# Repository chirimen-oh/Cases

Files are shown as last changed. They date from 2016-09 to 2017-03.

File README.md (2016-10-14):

# Cases
CHIRIMEN Board Case Repository / CHIRIMENボード用ケースリポジトリ

## ケースリポジトリの手順について
1. issueを作る
1. fork して pull-req  or  ブランチ して pull-req
1. Merge する
1. 基本的にmaster は、直接いじらない

※chirimen-oh.github.io と手順は同じ

----

# コード名の命名について

1. コード名はケース作者（デザイナー）が任意の段階で決める。先に決めておくことが望ましい
2. コード名に商標等権利が発生する言葉を含めてはならない（「CHIRIMEN」も含めて）
3. コード名に公序良俗に反する言葉を含めてはならない
4. コード名に既に登録されている他のケースと全く同じ名前は使わない
5. コード名に利用可能な文字は英数字及び`-`、`_`のみとする

# その他

## フォルダ名とreadme.md

- フォルダ名はコード名とする
- フォルダ名の直下に`readme.md`を配置する

`readme.md`にはケースの設計情報や作り方などの情報の他に、

1. ケースのコード名
2. 作者（デザイナー）
3. ステータス（作成中なのか、作成完了なのか）
4. ライセンス
5. ケースの簡単な紹介（特徴など）
6. ケースの組み立てマニュアル

上記内容を記載する事。

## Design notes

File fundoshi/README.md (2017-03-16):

---
case name: fundoshi
designer: D.F.Mac. (H.Kodama)
version: 0.12
status: Draft
---

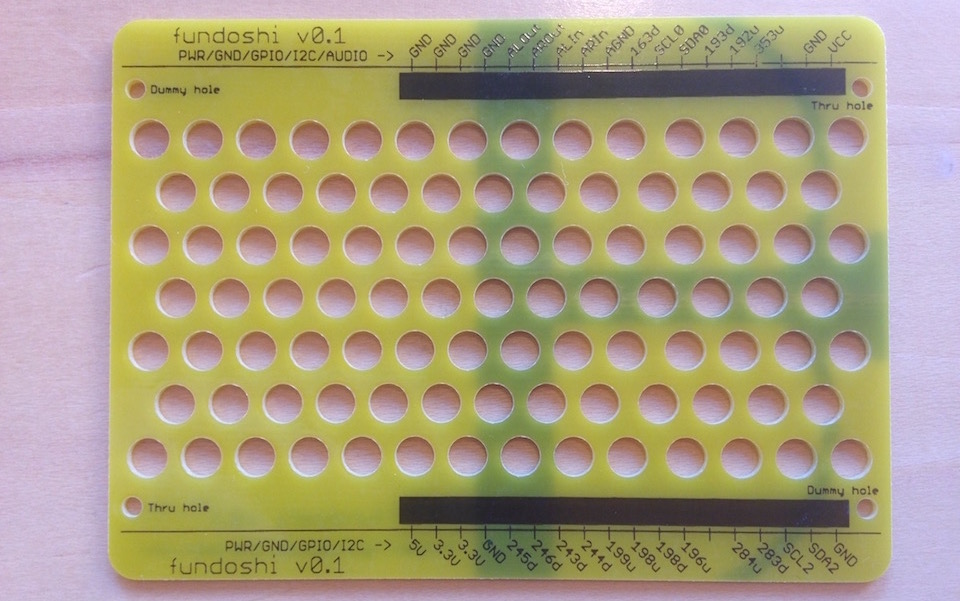
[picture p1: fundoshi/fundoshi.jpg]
fundosi-image


## desc

`fundoshi`はPCB1枚だけのシンプルなケースです。
上部は何もカバーせず底部のみカバーします。

## errata

v0.1及びv0.11にはFundoshiの印字に下記誤りがあります。

> v0.1のみ
>
> - CH1-8 が `198d` となっているが、`197d`の誤り
>
> v0.1、v0.11共通
> CH1-4 が `283d` となっているが、`283u`の誤り
> CH1-5 が `284u` となっているが、`284d`の誤り

上記誤りはv0.12で修正しています。

## design

Eagle 7.5で作成しています。詳細は下記を参照ください。

- [board(v0.12)](./eagle/CHIRIMEN-Fundoshi.brd)
- [Schematic(v0.12)※ブランクデータです](./eagle/CHIRIMEN-Fundoshi.sch)

### garber files

[Elecrow](https://www.elecrow.com/)用に出力したgarberファイルです。

- [v0.12](./garber-elecrow/v0.12)

## Make

[CHIRIMENにfundoshiを装着する (fabble)](http://fabble.cc/tadfmac/chirimen-fundoshi)

## License

[CHIRIME License](https://chirimen.org/license/)を参照ください。

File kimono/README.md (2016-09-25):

---
case name: kimono
designer: klaus (T.Fujieda)
version: 1.0
status: Publish
---

## desc

`kimono`はコンパクトなケースです。

アクリルボード4枚とボルト・ナットを使用してタフながら、各コネクタやピンにアクセスしやすくデザインされています。

case name「kimono」は、 [D.F.Mac.](https://github.com/tadfmac) 様に拝名をいただきました。

## design

Illustraorで設計し、レーザーカッターでアクリル加工しています。

- [Illustraor .ai](./chirimen_case4.ai)
- [Illustraor .svg](./chirimen_case4.svg)

### Parts

組み立てには下記パーツが必要です。

- 天板表(アクリル) ×1
- 天板裏(アクリル) ×1
- サイドステー(アクリル) ×2
- ボルト(2mm径) 長さ (15mm) ×3
- ボルト(2mm径) 長さ (8mm) ×1
- ボルト(2mm径) 長さ (6mm) ×2
- ナット(2mm径) 長さ (1.6mm) ×2
- ナット(2mm径) 長さ (3mm) ×9
 
2mm径長さ15mmのボルトは金属製しかないようです

## License

[Creative Commons License BY-SA 4.0 International](https://creativecommons.org/licenses/by-sa/4.0/deed.ja)

CHIRIMENの商標使用については、[CHIRIME License](https://chirimen.org/license/)を参照ください。

## README English
* Proto Type Case Making Process : [making-case-process-en.md](making-case-process-en.md)
* Parts List : [partsList-en.md](partsList-en.md)
* Assembly Process : [Assembly-procedure-en.md](Assembly-procedure-en.md)
* adobe illustrator Files : [chirimen_case4.ai](chirimen_case4.ai)
* SVG Files : [chirimen_case4.svg](chirimen_case4.svg)
* Case Build jpeg : [chirimen_case_build.jpg](chirimen_case_build.jpg)
* Case Build svg : [chirimen_case4_build.svg](chirimen_case4_build.svg)

## README 日本語
* 試作ケース製作プロセス：[making-case-process-ja.md](making-case-process-ja.md)
* パーツリスト：[partsList-ja.md](partsList-ja.md)
* 組み立て手順：[Assembly-procedure-ja.md](Assembly-procedure-ja.md)
* adobe illustrator ファイル：[chirimen_case4.ai](chirimen_case4.ai)
* SVG ファイル：[chirimen_case4.svg](chirimen_case4.svg)
* ケース組立図 jpeg形式：[chirimen_case_build.jpg](chirimen_case_build.jpg)
* ケース組立図 svg形式：[chirimen_case4_build.svg](chirimen_case4_build.svg)

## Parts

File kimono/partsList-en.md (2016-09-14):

## Parts list

### ◆ Acrylic board parts

| parts | number of need |
|:---|---|
| Acrylic Board (front : Logo) | 1 |
| Acrylic Board (back : Exhaust heat duct) | 1 |
| Side stay | 2 |

### ◆ Assembly parts

| parts | length:standard | diameter:standard  | number of need | site |
|:---|---|---|---:|:---:|
| Pan head mini screw | 15mm | M2:2mm | 3 | https://www.monotaro.com/p/0550/6977/ |
| POM Hexagonal nut spacers AS(Duracon)(packs) | 3mm | M2:2mm | 9 | https://www.monotaro.com/p/4226/3207/ |
| SPC-P Resin screw(PC/Pan head mini screw with a cross hole) | 6mm | M2:2mm | 2 | https://www.monotaro.com/p/4926/4993/ |
| (+)Pan head mini screw(Polycarbonate (transparency))  | 8mm | M2:2mm | 1 | https://www.monotaro.com/p/3579/5261/ |
| Hexagonal Nat 2 kind (stainless steel)  | 1.6mm | M2:2mm | 2 | https://www.monotaro.com/p/4221/7524/ |

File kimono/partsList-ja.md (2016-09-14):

## Parts list

### ◆ アクリル板パーツ

| パーツ | 必要個数 |
|:---|---|
| 天板（表：ロゴ） | 1 |
| 天板（裏：排熱ダクト） | 1 |
| サイドステー | 2 |

### ◆ 組み付けパーツ

| パーツ | 長さ：規格 | 径：規格  | 必要個数 | サイト |
|:---|---|---|---:|:---:|
| なべ小ねじ | 15mm | M2:2mm | 3 | https://www.monotaro.com/p/0550/6977/ |
| POM 六角両雌ねじスペーサー AS(ジュラコン)(パック品) | 3mm | M2:2mm | 9 | https://www.monotaro.com/p/4226/3207/ |
| SPC-P 樹脂ねじ(PC/十字穴付きなべ小ねじ) | 6mm | M2:2mm | 2 | https://www.monotaro.com/p/4926/4993/ |
| (+)鍋小ネジ(ポリカーボネート(透明))  | 8mm | M2:2mm | 1 | https://www.monotaro.com/p/3579/5261/ |
| 六角ナット 2種(ステンレス) | 1.6mm | M2:2mm | 2 | https://www.monotaro.com/p/4221/7524/ |

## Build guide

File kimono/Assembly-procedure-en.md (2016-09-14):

## Assembly Steps
1. About Parts
  * [Parts Lists](partsList-en.md) is Referred.
1. A board and acrylic parts are lined up.
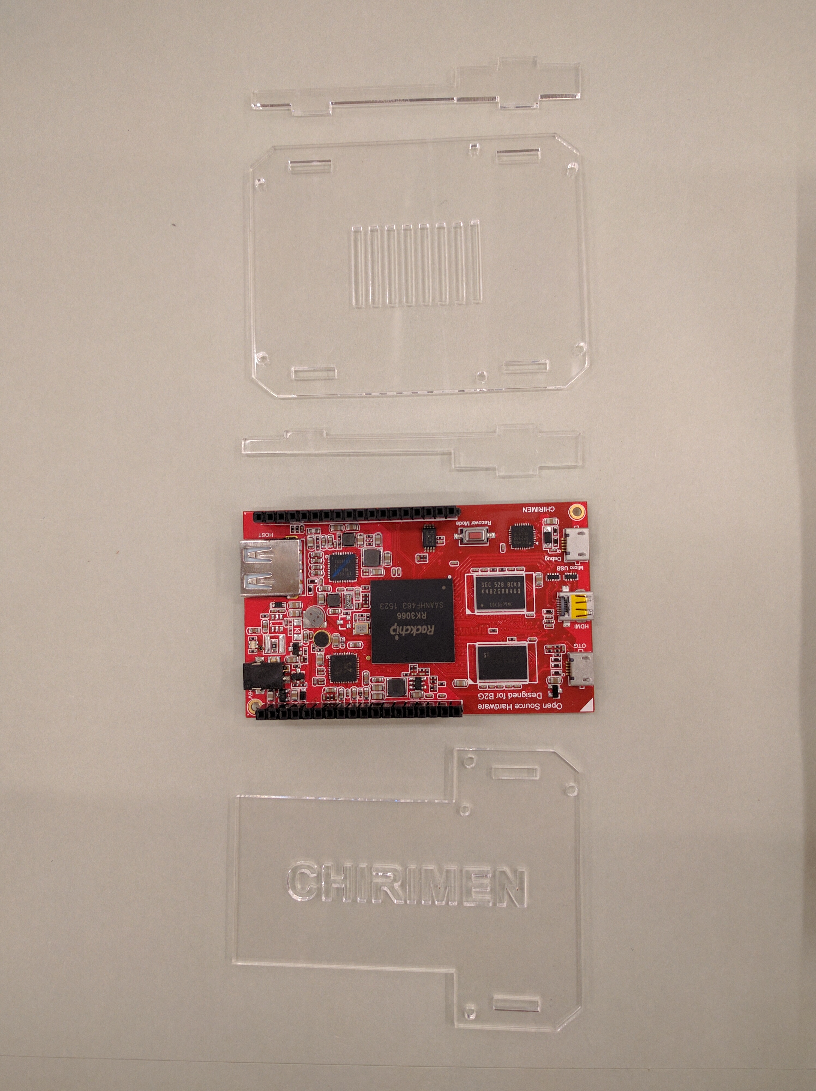
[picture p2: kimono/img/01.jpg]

1. Side stay is putted in Board (back : Exhaust heat duct) .
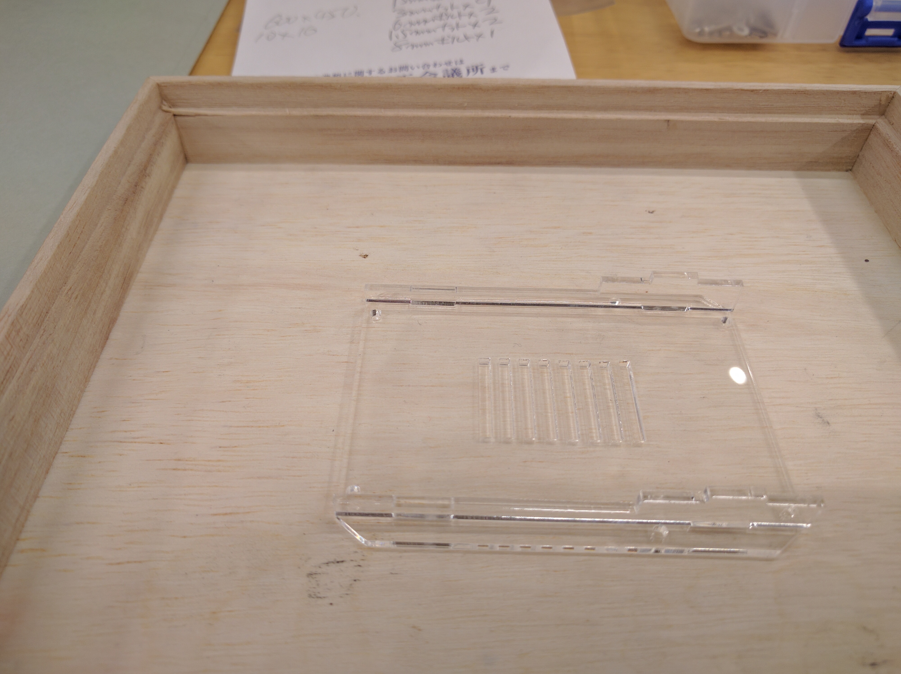
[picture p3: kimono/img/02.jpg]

1. Nuts and screw is used Assembly parts.
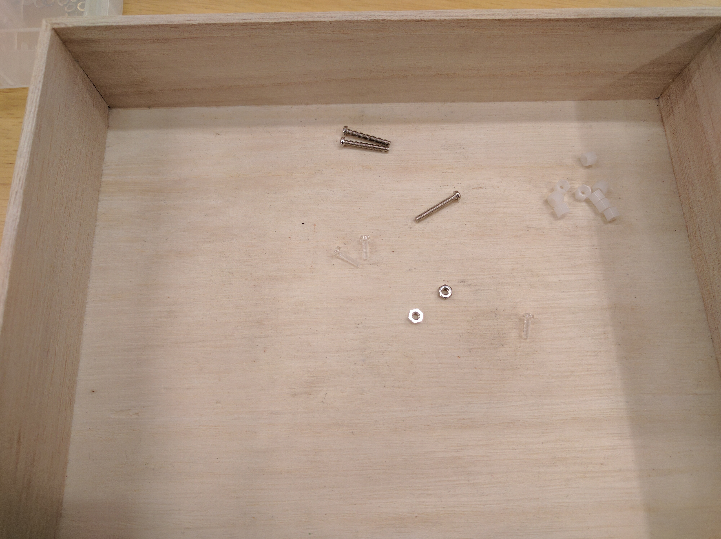
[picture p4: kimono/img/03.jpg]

1. 6mm length screw(2) is putted on Metal Nuts each 1.
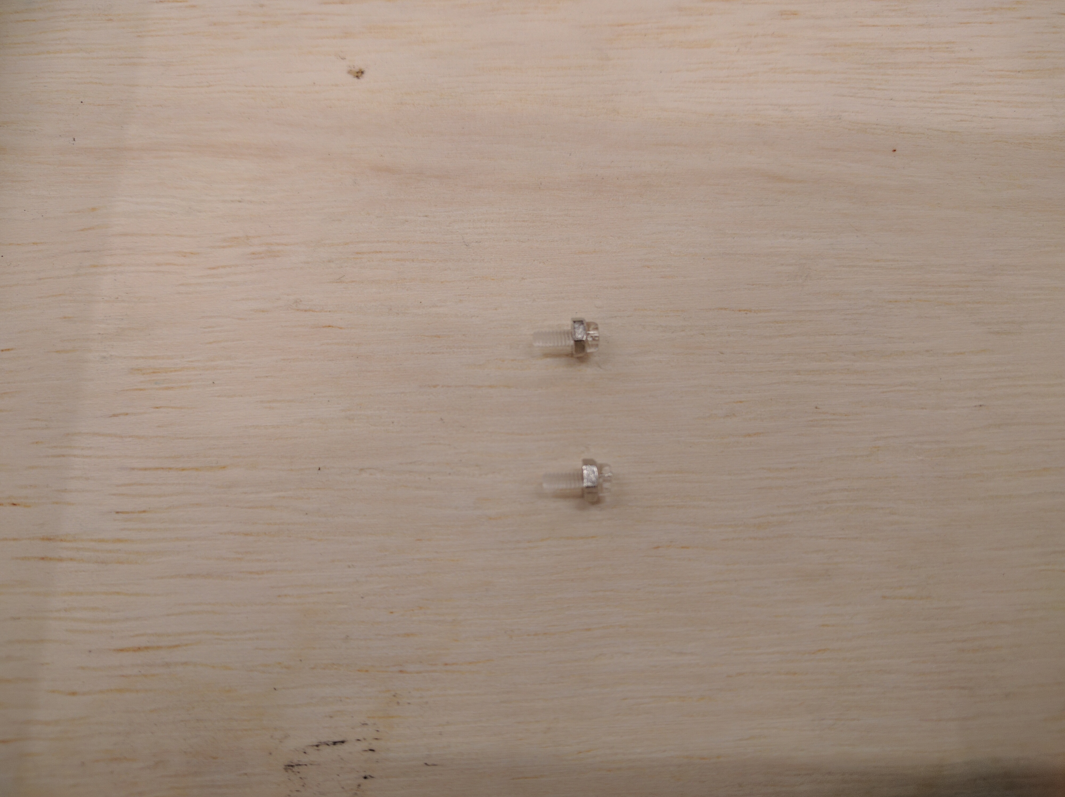
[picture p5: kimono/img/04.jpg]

1. 6mm length screw(2) is putted in Board (back : Exhaust heat duct) .
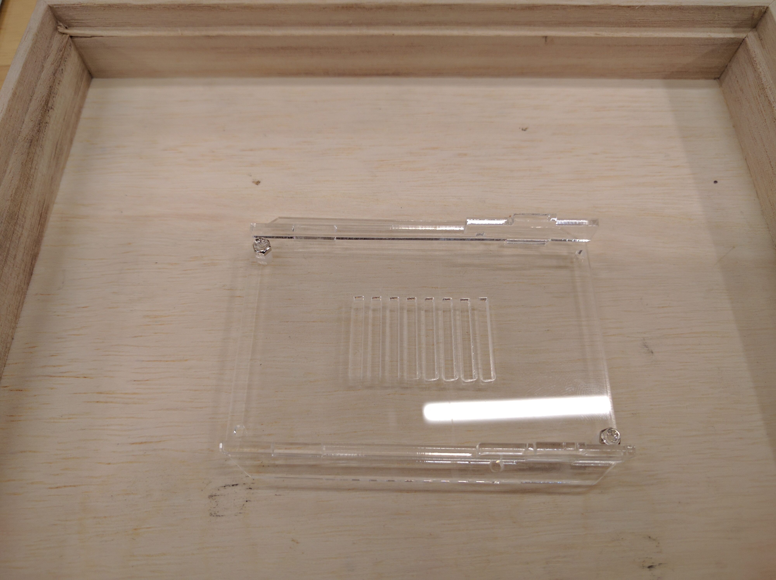
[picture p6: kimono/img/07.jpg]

1. Board (back : Exhaust heat duct) is reversed, White Nuts is putted on screw.
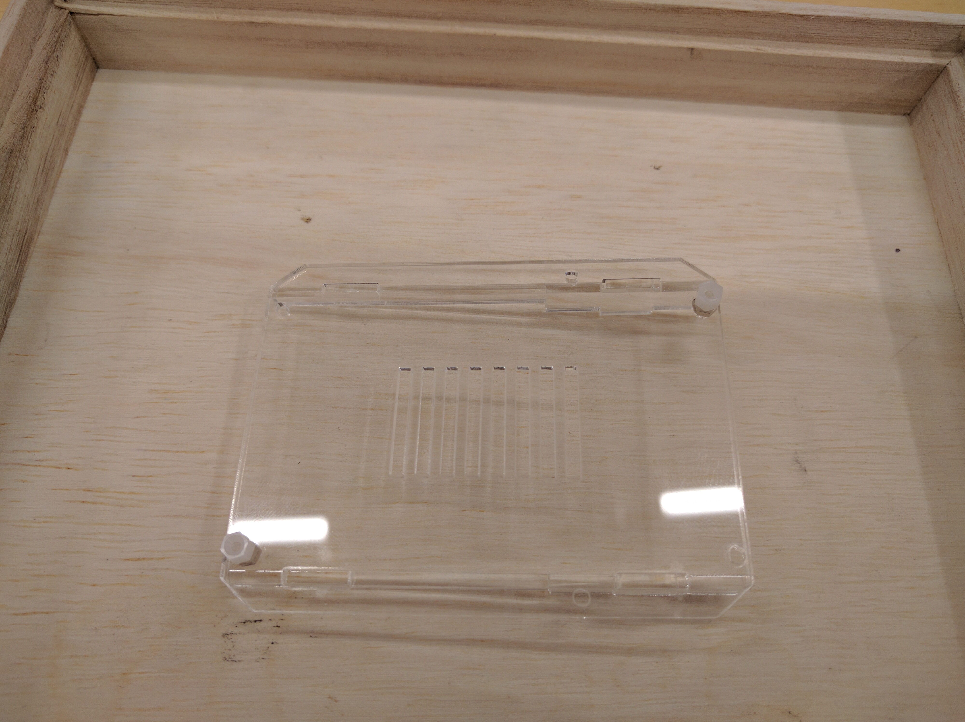
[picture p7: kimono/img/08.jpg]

1. 6mm length screw is putted at Around the point of a CHIRIMEN board Power Supply.
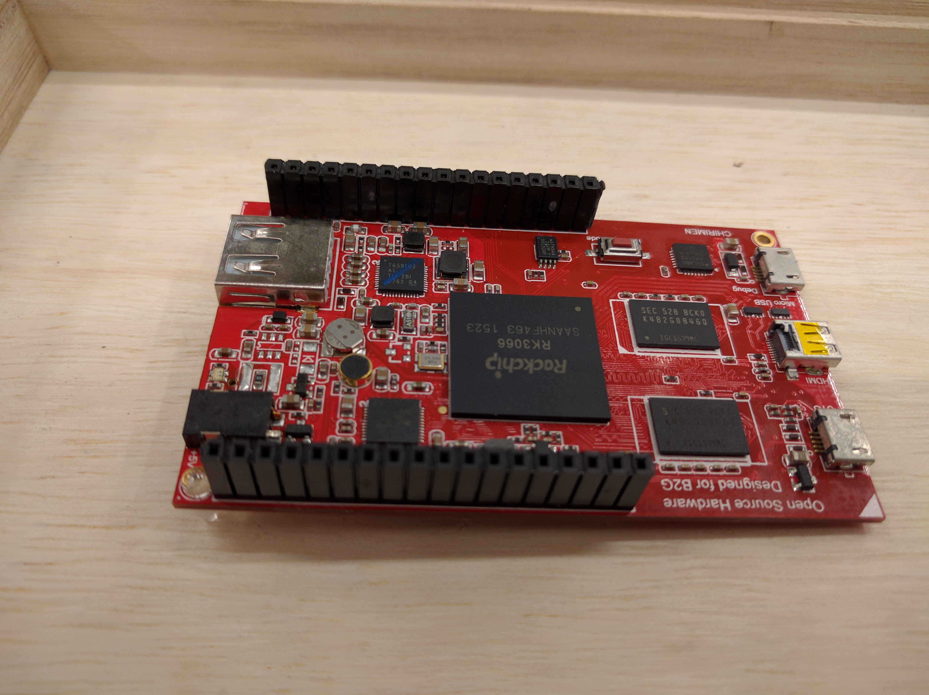
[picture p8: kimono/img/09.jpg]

1. CHIRIMEN Board is reversed, White Nuts is putted on screw.
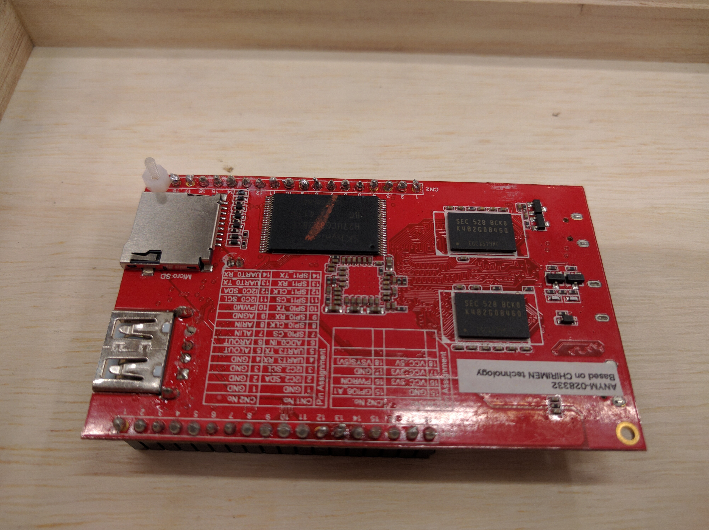
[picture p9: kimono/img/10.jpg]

1. Board (front : Logo) and 15mm screw(1) White Nuts(2) stand by.
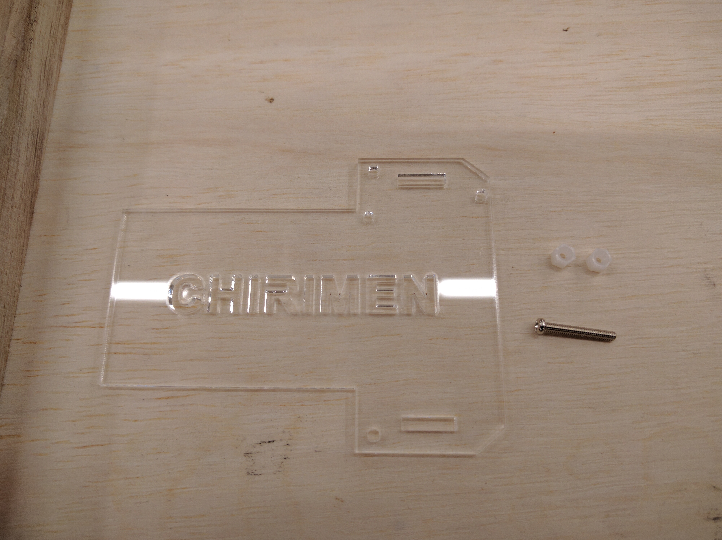
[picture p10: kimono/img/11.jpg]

1. Like a Under Picture, Board (front : Logo) is putted in 15mm length screw(1) ,  
   After White Nuts is putted on screw.
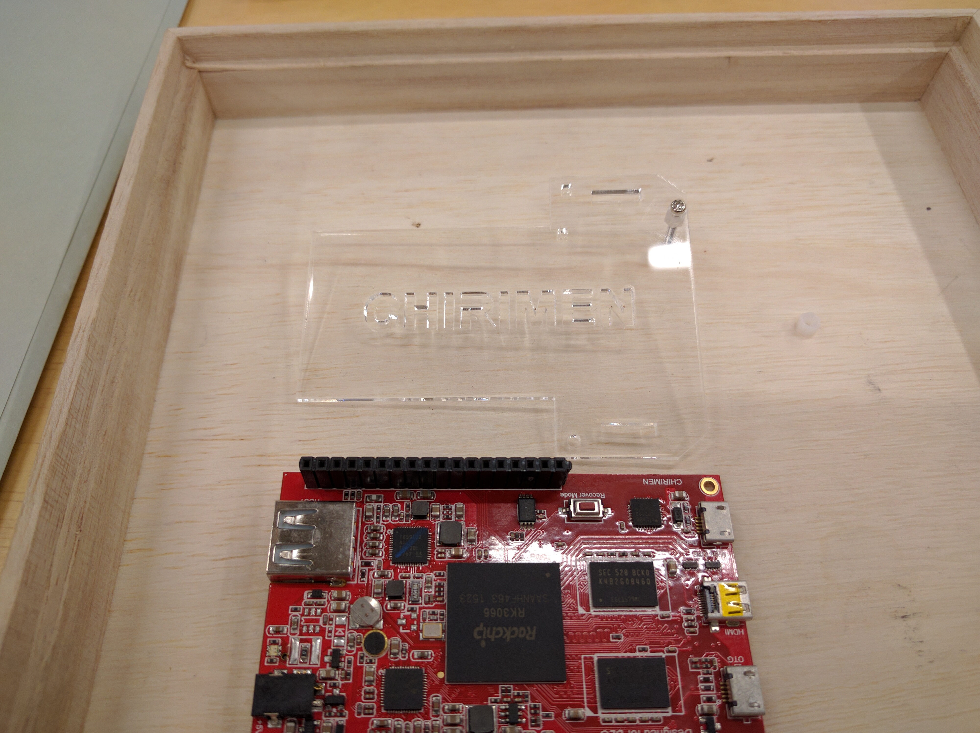
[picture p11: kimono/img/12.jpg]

1. And More, Like a Under Picture, Board (front : Logo) is putted in Hole of Recover Mode SW Right Side,  
  After White Nuts is putted on screw.
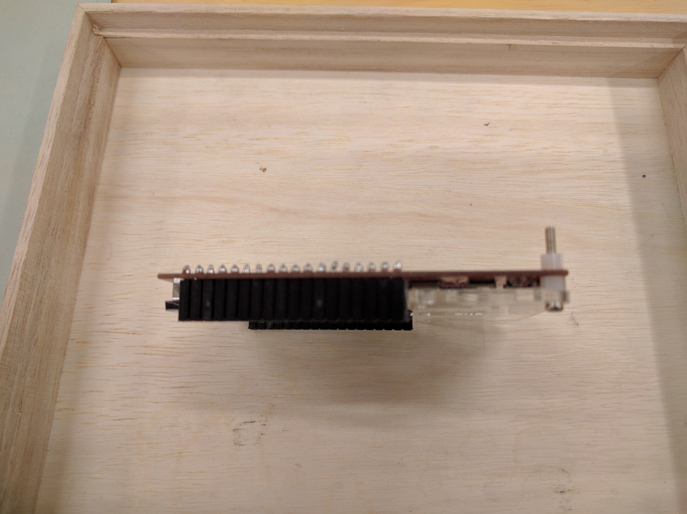
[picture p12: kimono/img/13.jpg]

1. CHIRIMEN Board is reversed, Like a Under Picture.
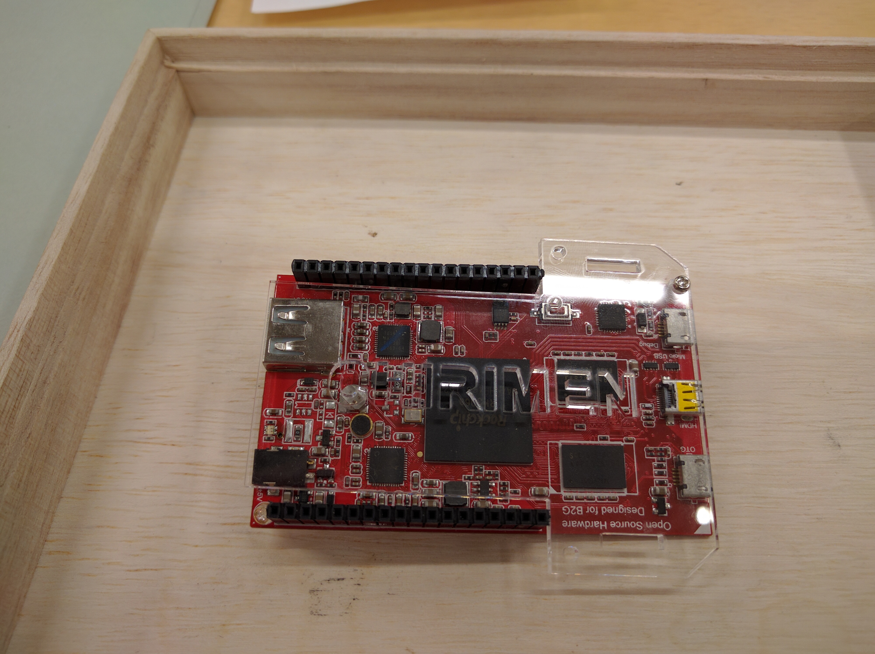
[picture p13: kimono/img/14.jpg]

1. Board (front : Logo) and Board (back : Exhaust heat duct) is picked up.  
  Like a Under Picture.
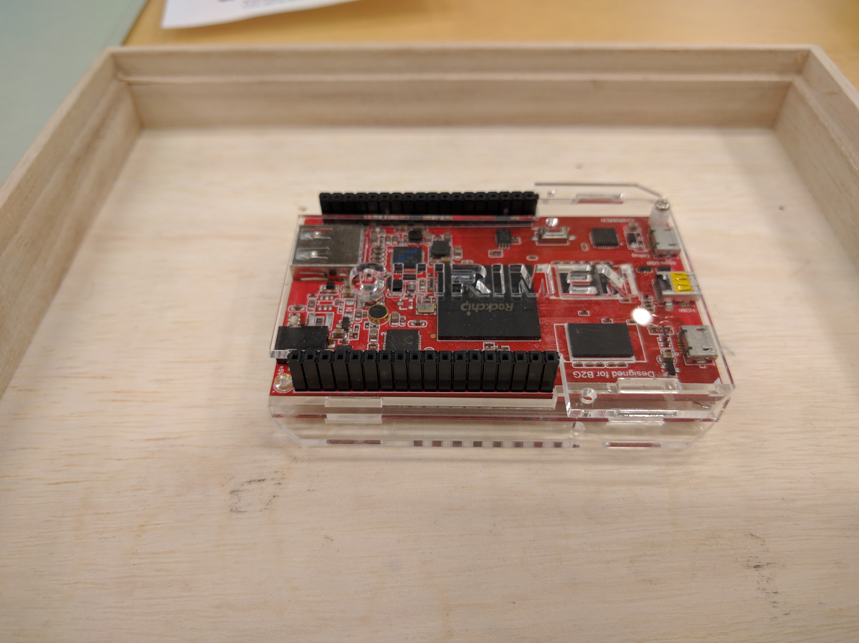
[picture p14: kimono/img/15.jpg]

1. CHIRIMEN Board and Acrylic board(front and back) is reversed, Like a Under Picture.
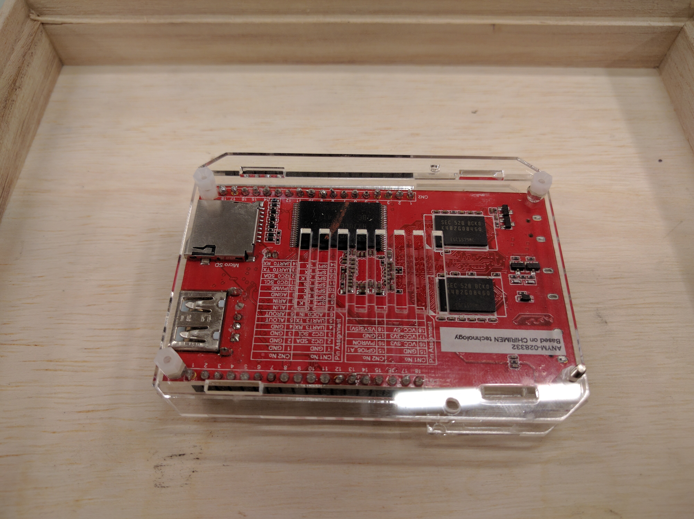
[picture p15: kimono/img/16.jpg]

1. Like a Over Picture, CHIRIMEN Board of The lower right side, White Nuts is putted on screw.
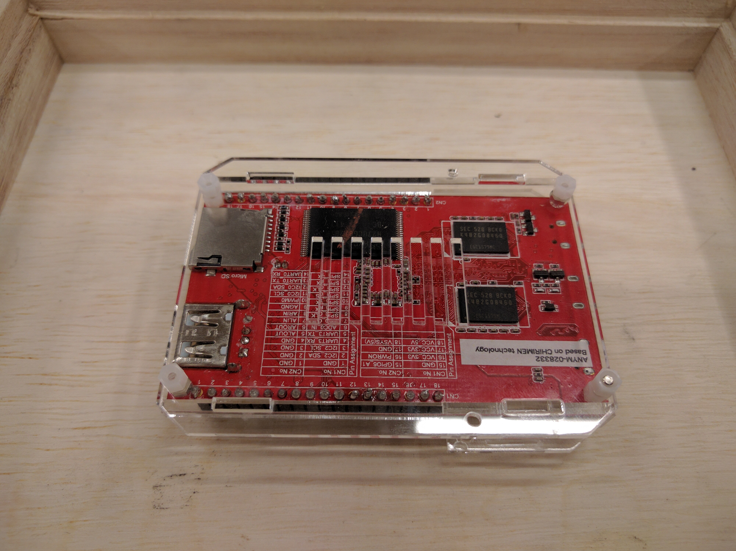
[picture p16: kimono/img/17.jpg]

1. Reversed, Remaining these 15mm length screw is putted in Board (front : Logo).
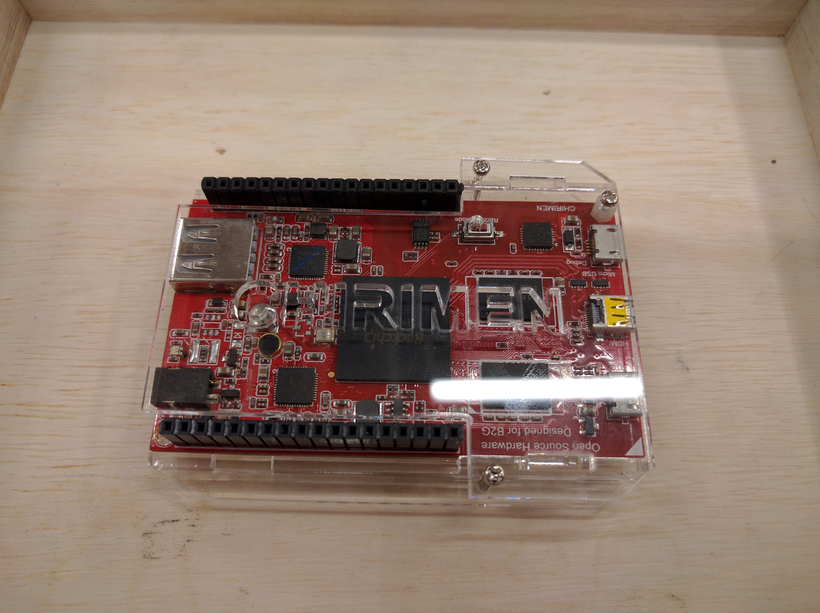
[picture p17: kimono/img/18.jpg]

1. One More Reversed, Remaining these  White Nuts is putted on these 15mm length screw(2).
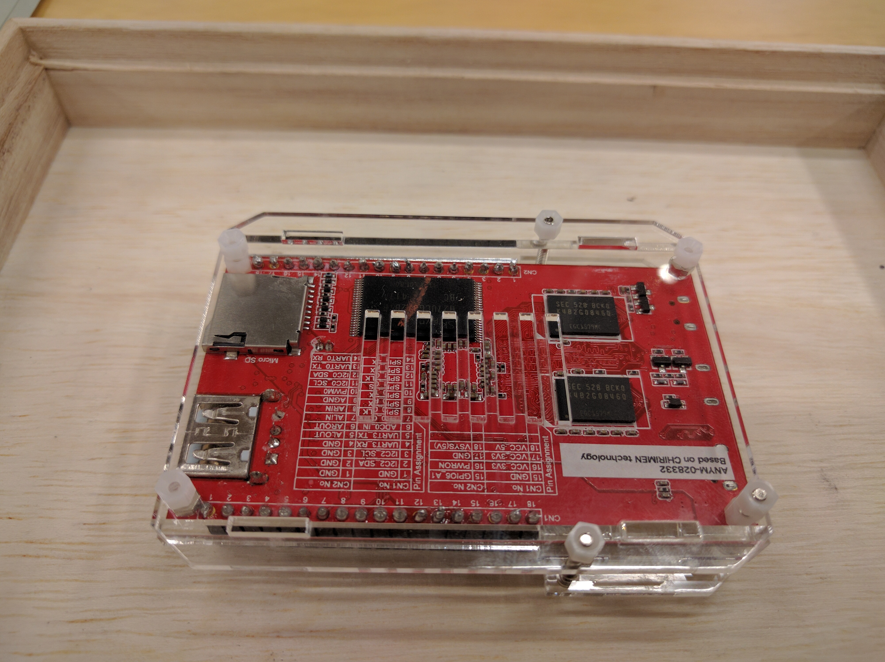
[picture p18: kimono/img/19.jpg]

1. At Last Reversed, Case is Assemblying to Finish.
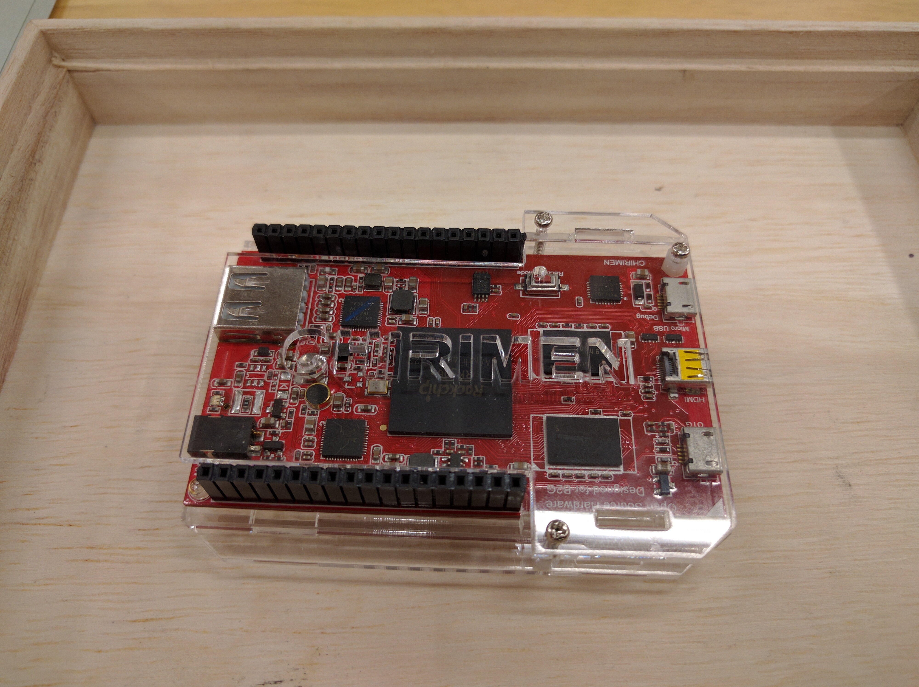
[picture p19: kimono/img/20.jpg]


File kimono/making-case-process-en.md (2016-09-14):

## Proto Type Case Making Process
1. Case is designed by adobe illustrator.
1. Design Data is Exporting SVG Files type.
1. The material : Acrylic board The thickness is 2mm stand by.
1. Making Machine is this.(these site is japanese only)  
  [世界最大の組立式CO2レーザー加工機(カッター) Smart Laser CO2](http://www.smartdiys.com/smart-laser-co2/)
1. These Machinery and materials are forwarded data and   
   made along a manual.(these site is japanese only)  
  [ソフトウェアの使い方 | CO2レーザー加工機(カッター)](http://www.smartdiys.com/manual/smart-laser-co2-use-softwera/)

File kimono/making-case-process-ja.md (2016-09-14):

## 試作ケース製作プロセス
1. adobe illustrator などで、ケースをデザインします。
1. デザインデータを SVG ファイル形式で、出力します。
1. 材料：アクリル板 厚さ2mm を用意します。
1. 製作機材は、下記の機材を使用。  
  [世界最大の組立式CO2レーザー加工機(カッター) Smart Laser CO2](http://www.smartdiys.com/smart-laser-co2/)
1. 上記機材をマニュアルに沿って、データ転送して製作します。  
  [ソフトウェアの使い方 | CO2レーザー加工機(カッター)](http://www.smartdiys.com/manual/smart-laser-co2-use-softwera/)

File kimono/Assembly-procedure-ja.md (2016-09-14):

## 組み立て手順
1. 部品について
  * [パーツリスト](partsList-ja.md) を参照
1. ボード、アクリルパーツを並べます。
chirimen_dev_conf
1. サイドステーを天板（裏：排熱ダクト）に差し込みます。
chirimen_dev_conf
1. 組み立てに使うナット、ネジです。
chirimen_dev_conf
1. 6mm ネジ（2本）に金属ナットを１つずつ装着します。
chirimen_dev_conf
1. この6mm ネジ（2本）を下図のように天板（裏：排熱ダクト）に差し込みます。
chirimen_dev_conf
1. 天板（裏：排熱ダクト）を裏側にして、白いナットを差し込みます。
chirimen_dev_conf
1. CHIRIMEN ボードの電源付近の穴に6mm ネジを差し込みます。
chirimen_dev_conf
1. CHIRIMEN ボードを裏側にして、白いナットを差し込みます。
chirimen_dev_conf
1. 天板（表：ロゴ）と15mm ネジ（1本）白いナット（2個）用意します。
chirimen_dev_conf
1. 下図のように天板（表：ロゴ）に15mm ネジ通してから、白いナット（1個）ねじ込みます。
chirimen_dev_conf
1. 更に下図のように天板（表：ロゴ）を Recover Mode SW の右側にある穴に通してから、白いナット（1個）をねじ込みます。
chirimen_dev_conf
1. ひっくり返すと下図のようになります。
chirimen_dev_conf
1. CHIRIMEN ボード付の天板（表：ロゴ）と先程の天板（裏：排熱ダクト）合わせ込むと下図のようになります。
chirimen_dev_conf
1. CHIRIMEN ボード付の天板（表・裏）裏側にすると下図のようになります。
chirimen_dev_conf
1. 上図の CHIRIMEN ボードの右下側の15mm ネジに白いナット（1個）をねじ込みます。
chirimen_dev_conf
1. 裏返しにして、残りの15mm ネジを天板（表：ロゴ）に差し込みます。
chirimen_dev_conf
1. 再度裏返しにして、残りの15mm ネジをの15mm ネジに白いナット（2個）をねじ込みます。
chirimen_dev_conf
1. 最後に裏返しにして、ケースの組み立てが完了しました。
chirimen_dev_conf

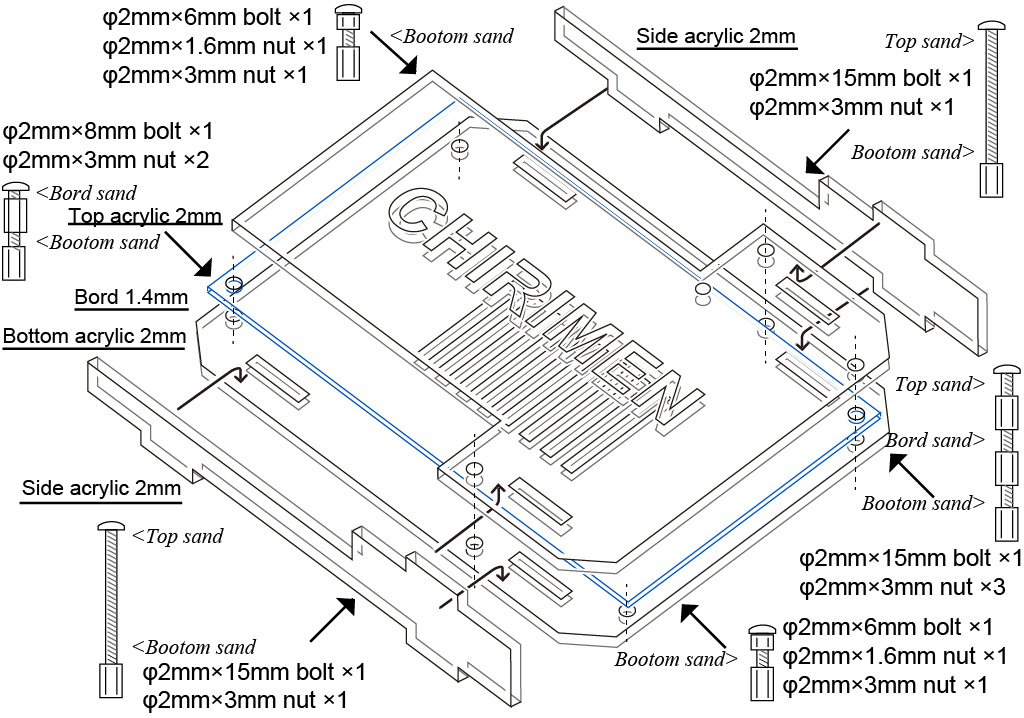
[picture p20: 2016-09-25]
kimono/chirimen_case_build.jpg

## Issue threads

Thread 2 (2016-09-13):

試作ケースのコード名ルール

gurezo, 2016-09-13:
試作ケースのコード名ルールの策定をする

tadfmac, 2016-09-15:
# コード名の命名について

コード名の命名ルールについて、案を書きます。ご指摘等お待ちしています。
基本的には必要最低限にしたいというのが希望です。

1. コード名はケース作者（デザイナー）が任意の段階で決める。先に決めておくことが望ましい
2. コード名に商標等権利が発生する言葉を含めてはならない（「CHIRIMEN」も含めて）
3. コード名に公序良俗に反する言葉を含めてはならない
4. コード名に既に登録されている他のケースと全く同じ名前は使わない
5. コード名に利用可能な文字は英数字及び`-`、`_`のみとする

# その他

## フォルダ名とreadme.md

コード名とは別ですが必要最低限という意味で下記を入れた方がいいとおもいます。

- フォルダ名はコード名とする
- フォルダ名の直下に`readme.md`を配置する

`readme.md`にはケースの設計情報や作り方などの情報の他に、

1. ケースのコード名
2. 作者（デザイナー）
3. ステータス（作成中なのか、作成完了なのか）
4. ライセンス

を記載した方が良いとおもいます。

gurezo, 2016-09-15:
上記５と似ていますが、ケースの組み立てマニュアルも有った方が良いと思います。

tadfmac, 2016-10-12:
とりあえず、ルールBookはwikiにでも移動してCloseしませんか?

gurezo, 2016-10-14:
直下のREADMEに追記したので、close

Closed 2016-10-14.

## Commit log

2016-09-13 リポジトリルール追記
2016-09-14 コメント追記
2016-09-14 case design add
    svg File Add
2016-09-14 構成パーツ追記
2016-09-14 表記修正
2016-09-14 個数修正
2016-09-14 ケース組み立て手順作成
2016-09-14 試作ケース製作プロセス追記
2016-09-14 説明用READMEファイル追加
2016-09-14 翻訳漏れ、誤字修正
2016-09-14 case Instruction drow
    drawing instrustion
2016-09-15 ケース組み立てファイル情報追記
2016-09-15 ファイル名・リンクに不備があったので、修正
2016-09-15 add eagle files
    [CHIRIMEN-Fundoshi.brd, CHIRIMEN-Fundoshi.sch]
2016-09-18 update board file
    [CHIRIMEN-Fundoshi.brd]
2016-09-18 add garber files, update readme.md
    [CHIRIMEN-Fundoshi.GBL, CHIRIMEN-Fundoshi.GBO, CHIRIMEN-Fundoshi.GBS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]
2016-09-18 fix board/garber file
    [CHIRIMEN-Fundoshi.brd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]
2016-10-14 フォルダ名修正
2016-10-14 #2 試作ケースのコード名ルール #2対応
2017-03-16 fix print on CH1-4 and CH1-5
    [CHIRIMEN-Fundoshi.brd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]
